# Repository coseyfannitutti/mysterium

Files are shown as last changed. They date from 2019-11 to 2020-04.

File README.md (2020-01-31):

# MYSTERIUM
**TKL keyboard that can be entirely assembled using only through hole components, including usb type c**

**[BOM, Build Guide, and Flashing Information](./doc)**

**Kits available at [cftkb.com](https://www.cftkb.com)**

**[Optional High Profile Lasercut Acrylic Case](./case)**

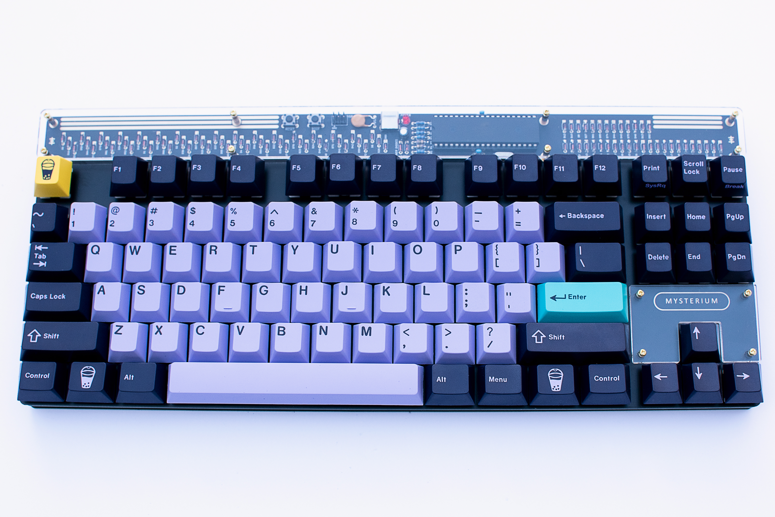
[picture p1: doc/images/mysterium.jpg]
mysterium

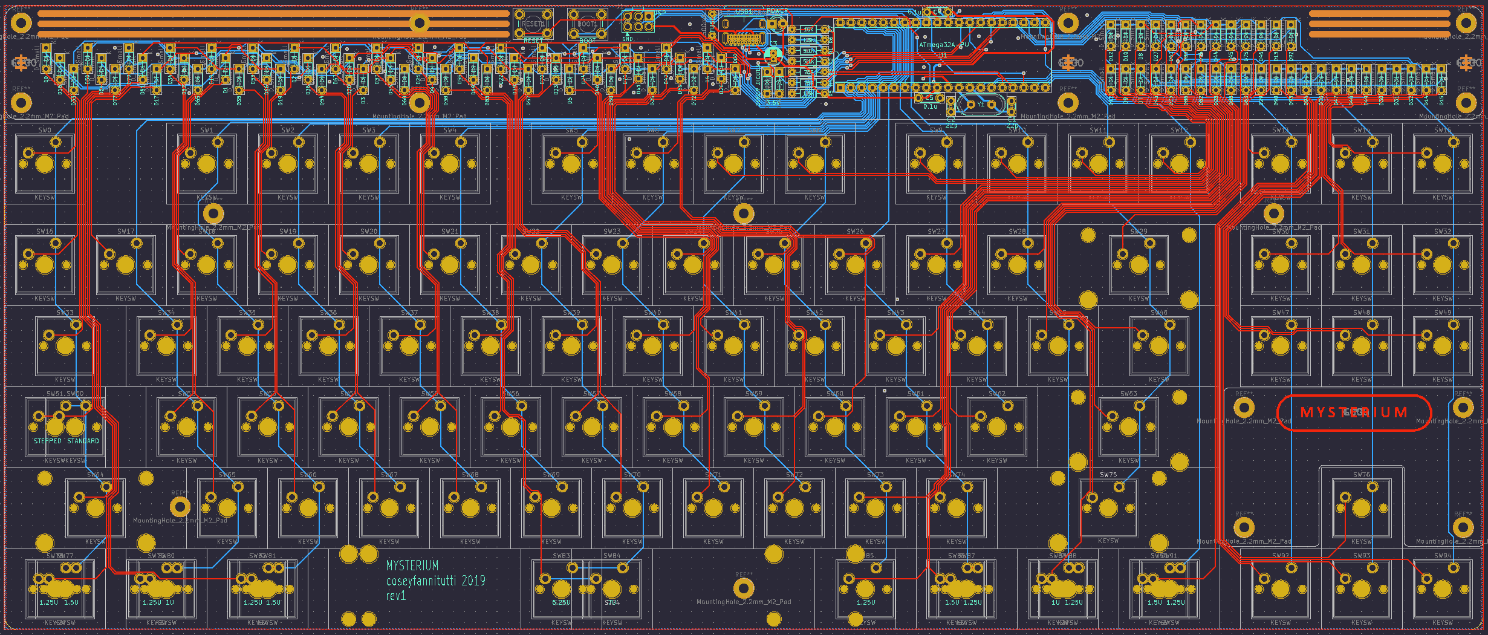
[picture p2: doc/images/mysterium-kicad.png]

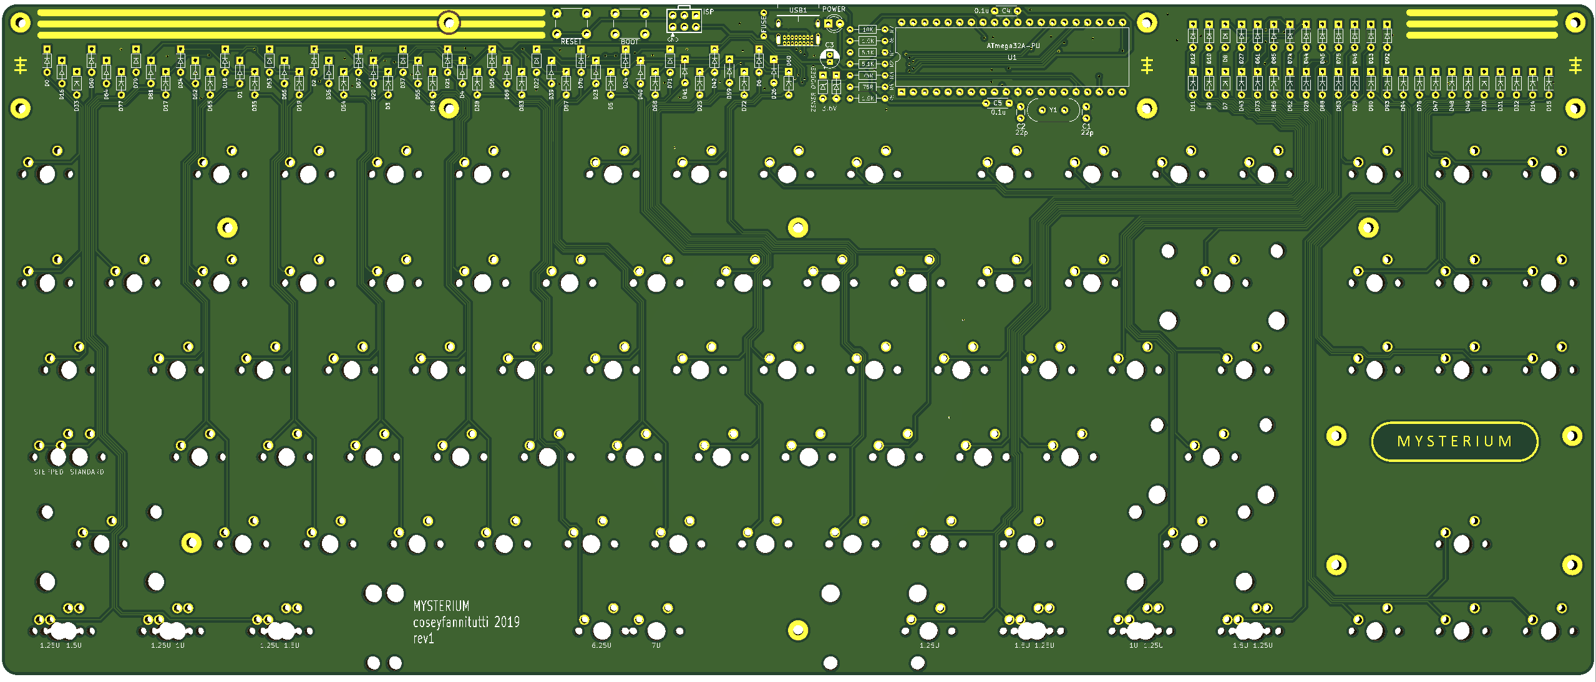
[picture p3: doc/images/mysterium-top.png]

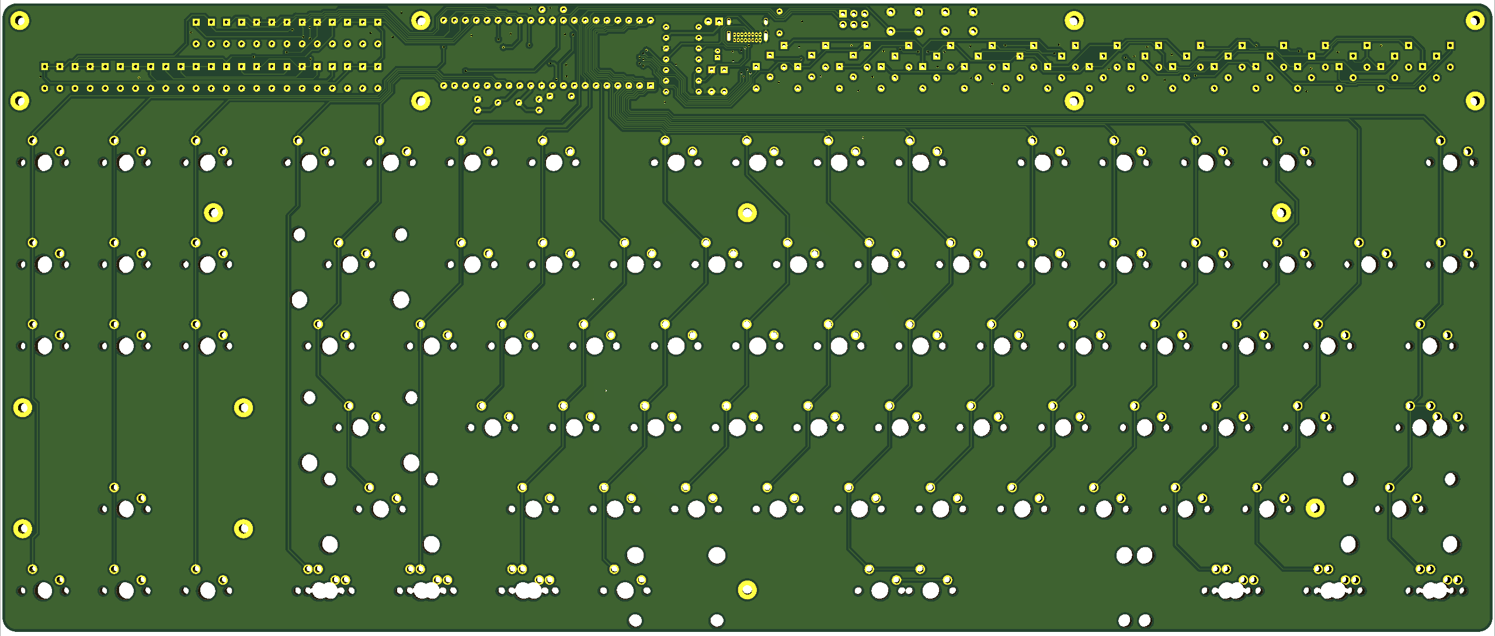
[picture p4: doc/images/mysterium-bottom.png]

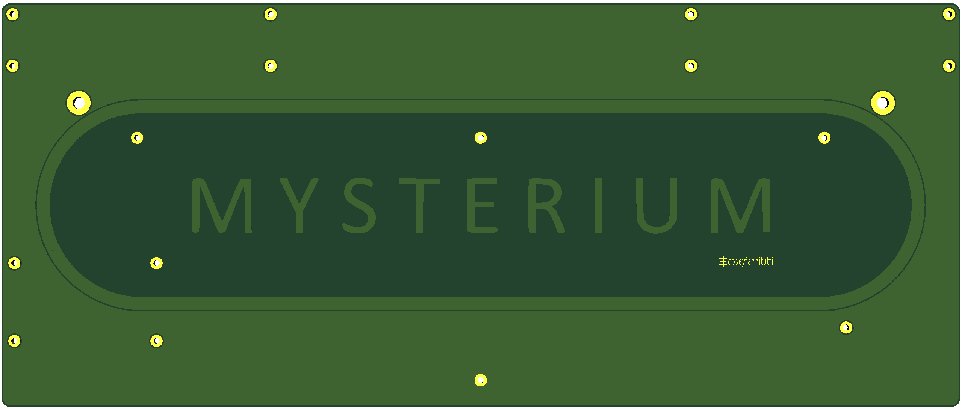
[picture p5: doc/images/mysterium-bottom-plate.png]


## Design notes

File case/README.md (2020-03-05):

# Lasercut Acrylic Case with POM Plate

***This is case is OPTIONAL and not required. The kit has everything you need for a fully functional keyboard.
This case uses a different plate and is NOT compatible with the plate included in the kit.
If you have already soldered switches, you will need to desolder them and swap the plate.***

***I recommend using [Ponoko](https://www.ponoko.com) to cut the pieces. They have all of the correct/required thicknesses and materials in stock and have the best pricing that I have found for multiple one-off parts. Use clear acrylic for the full range of thickness options and Delrin (POM) for the plate. For proper fit please ensure you use the correct dimensions and material thicknesses noted below. mysterium-top-1.dxf must be clear for component window. 3mm pieces will have full range of color options. 4.5mm open layer will have limited color choices but will only be visible from the side.***

***Ponoko's automatic size detection when uploading is not flawless, so be sure to manually enter the dimensions below.***

## Part Dimensions/Thickness (Top to Bottom)
1. mysterium-top-1.dxf - 363.7 x 162.6 mm - ***2mm thickness clear acrylic***
2. mysterium-top-2.dxf ***x2 needed*** - 363.7 x 162.6 mm - ***3mm thickness acrylic (Matte/frosted or color recomended for winkeyless version to hide plate hole.)***
3. mysterium-plate.dxf - 363.7 x 162.6 mm - ***1.5mm thickness DELRIN(POM)*** Can be black or white.
4. mysterium-open-layer.dxf - 363.7 x 162.6 mm - ***4.5mm thickness acrylic***
5. mysterium-closed-layer.dxf - 363.7 x 162.6 mm - ***3mm thickness acrylic***
6. mysterium-bottom.dxf - 363.7 x 162.6 mm - ***3mm thickness acrylic***
7. mysterium-foot-1.dxf - 323.7 x 32mm - ***3mm thickness acrylic***
8. mysterium-foot-2.dxf - 319.7 x 28mm - ***3mm thickness acrylic***
9. mysterium-foot-3.dxf - 315.7 x 24mm - ***3mm thickness acrylic***
10. mysterium-foot-4.dxf - 311.7 x 20mm - ***3mm thickness acrylic***

## Screws and Standoffs
1. [32x m2x6mm screws](https://www.aliexpress.com/item/32870342767.html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,searchweb201602_7,searchweb201603_53)
2. [12x m2x14mm standoffs](https://www.aliexpress.com/item/32968906213.html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,searchweb201602_7,searchweb201603_53)
3. [4x m2x8mm standoffs](https://www.aliexpress.com/item/32968906213.html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,searchweb201602_7,searchweb201603_53)

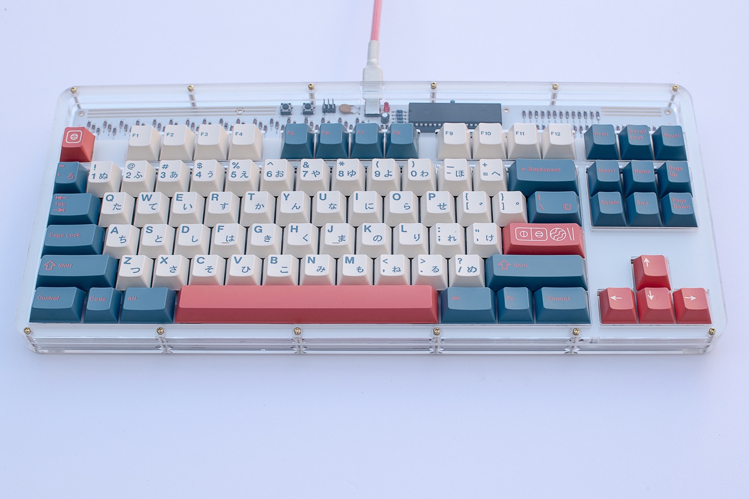
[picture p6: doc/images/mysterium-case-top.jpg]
mysterium

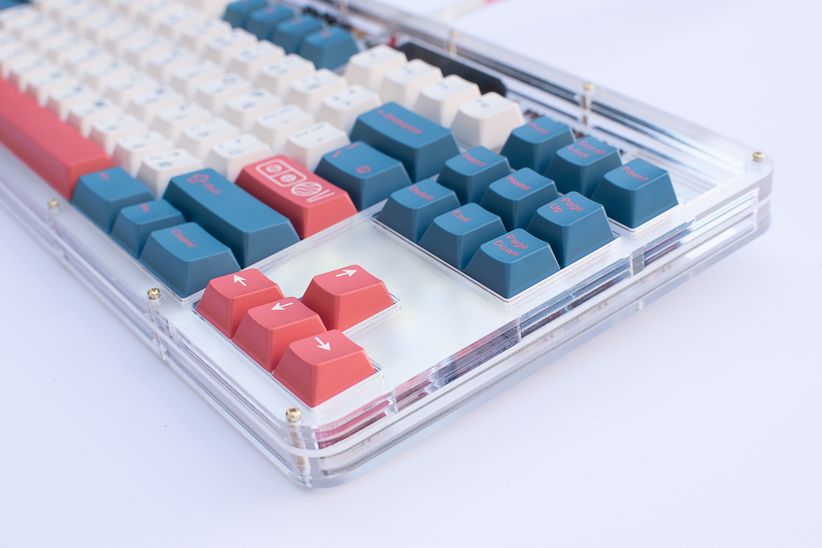
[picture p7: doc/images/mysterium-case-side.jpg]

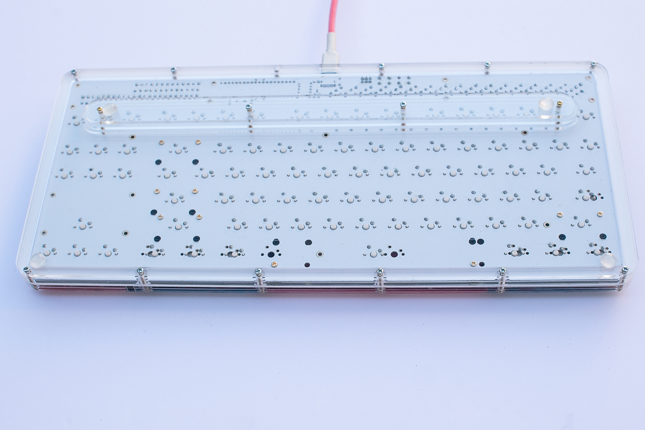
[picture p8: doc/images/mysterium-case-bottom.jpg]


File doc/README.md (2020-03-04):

# MYSTERIUM

mysterium

**[Build Guide](https://static1.squarespace.com/static/5c533d33348cd92b886e544d/t/5e5fc8299979957341bf18a8/1583335468613/MYSTERIUM+BUILD+GUIDE.pdf)**

**[QMK Toolbox Flashing Guide (Recommended)](https://static1.squarespace.com/static/5c533d33348cd92b886e544d/t/5e4771362bab65763e8d1e4c/1581740343418/MYSTERIUM+FLASHING+GUIDE.pdf)**

**[Command Line Flashing Guide (Advanced)](https://static1.squarespace.com/static/5c533d33348cd92b886e544d/t/5e33a3895318fc520982d4a1/1580442505724/MYSTERIUM+FLASHING+GUIDE+-+COMMAND+LINE.pdf)**

**[Bootloader](./bootloader)**

**[BOM (Parts List)](https://octopart.com/bom-tool/wr8C8imk)**

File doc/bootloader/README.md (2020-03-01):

# Bootloader

## If you buy a kit from cftkb.com your microcontroller already has the bootloader flashed and you do not need this.

This project uses USBaspLoader as the usb bootloader on the atmega32a.
- My custom bootloader:   
https://github.com/coseyfannitutti/USBaspLoader/tree/atmega32a
  - Please ensure you are in the atmega32a branch of my fork of the USBaspLoader repository when downloading.
  - Follow the directions in the readme for directions on setting up the build environment for your operating system as well as flash instructions.
  - Makefile.inc sets flashing device as usbtiny, as I use a sparkfun pocket avr programmer. If you need to use another programmer please edit line 41 of Makefile.inc accordingly. Only edit Makefile.inc, and NEVER directly edit the actual Makefile.
  - Commands for flashing once build environment is set up:
  
	```make flash``` (flashes makefile)
  
  	```make fuse``` (sets fuses for microcontroller)
  
## Enter bootloader mode
1. Press and hold ```BOOT``` switch
2. Tap ```RESET``` switch
3. Release ```BOOT``` switch

Alternatively, you can hold ```BOOT``` switch while inserting the USB cable.

If you have successfully entered bootloader mode you should see USBaspLoader in device manager or as a connected device in QMK Toolbox.

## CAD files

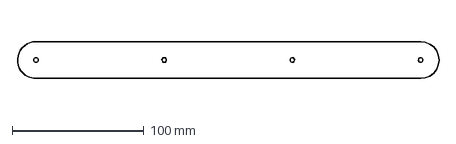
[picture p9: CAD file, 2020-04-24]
case/standard/mysterium-foot-2.dxf
321.4 x 28.0 mm

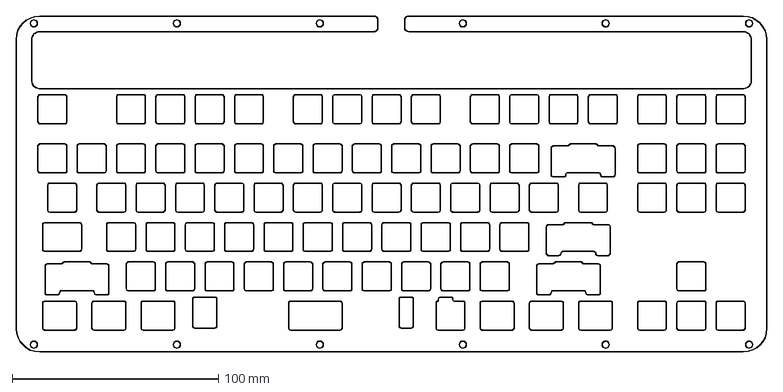
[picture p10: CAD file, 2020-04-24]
case/winkeyless/mysterium-plate.dxf
363.7 x 162.6 mm

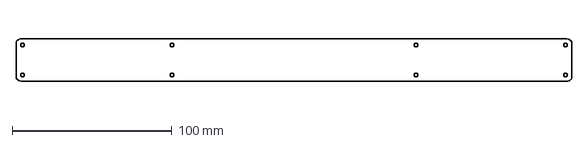
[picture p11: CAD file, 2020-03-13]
mysterium-acrylic-guard.dxf
347.7 x 26.8 mm

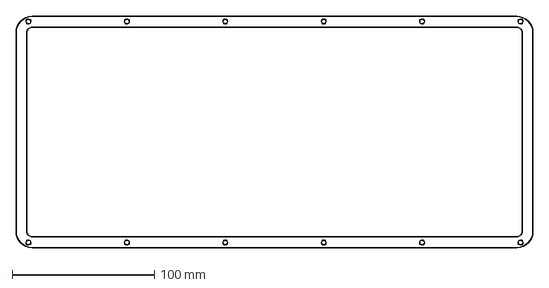
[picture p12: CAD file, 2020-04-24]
case/standard/mysterium-closed-layer.dxf
363.7 x 162.6 mm

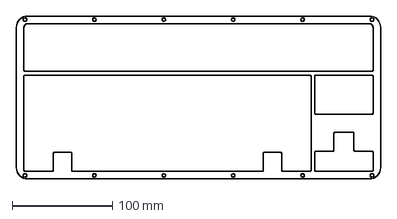
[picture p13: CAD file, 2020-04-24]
case/winkeyless/mysterium-top-2-wkl.dxf
363.7 x 162.6 mm

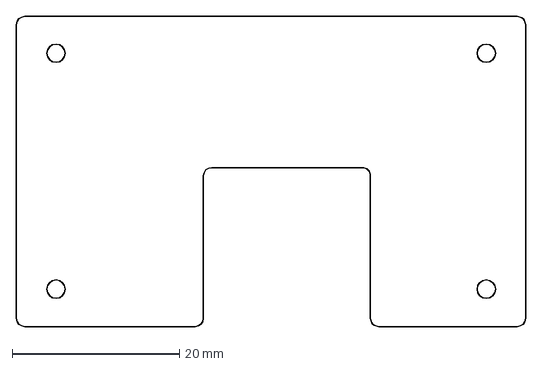
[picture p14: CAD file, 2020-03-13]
mysterium-nav-acrylic.dxf
61.0 x 37.2 mm

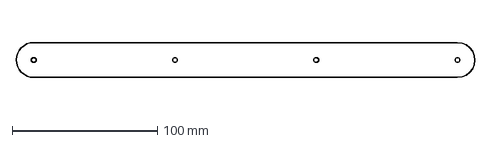
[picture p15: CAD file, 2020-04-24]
case/standard/mysterium-foot-3.dxf
316.2 x 24.0 mm

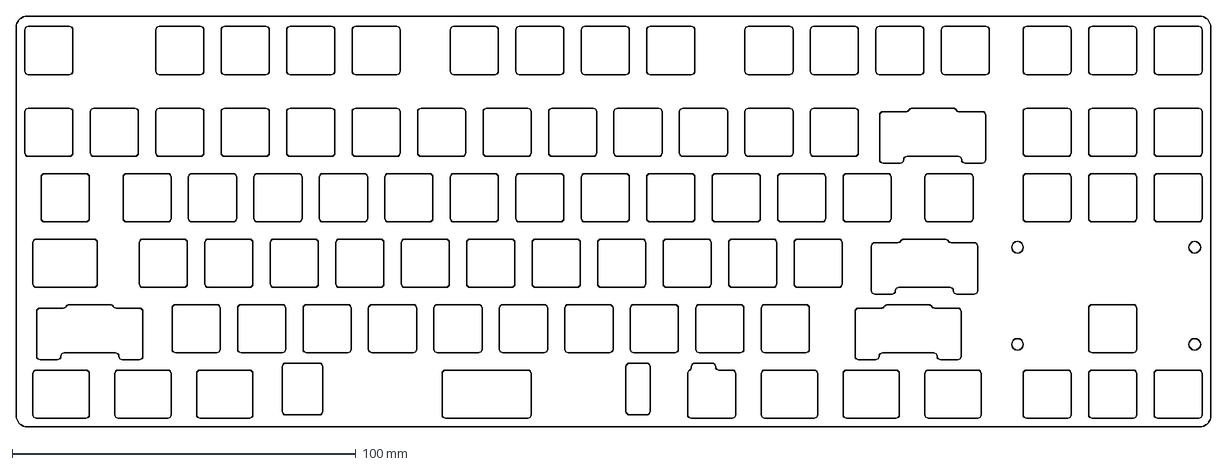
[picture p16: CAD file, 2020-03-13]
mysterium-kit-plate.dxf
347.7 x 119.5 mm

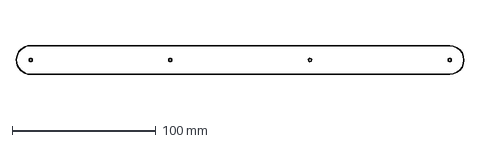
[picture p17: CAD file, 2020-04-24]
case/standard/mysterium-foot-4.dxf
312.1 x 20.0 mm

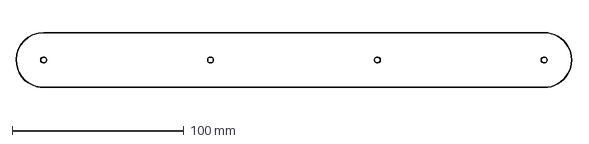
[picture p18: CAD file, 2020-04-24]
case/standard/mysterium-foot-1.dxf
324.4 x 32.0 mm

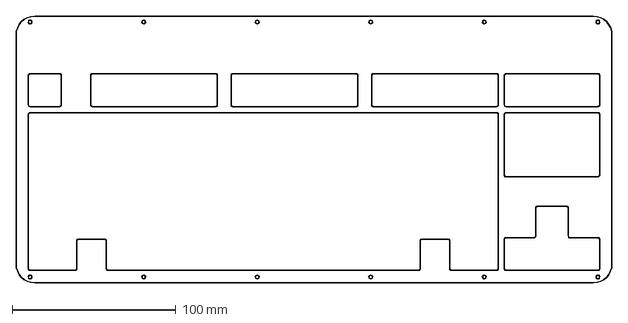
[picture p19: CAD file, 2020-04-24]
case/winkeyless/mysterium-top-1-wkl.dxf
363.7 x 162.6 mm

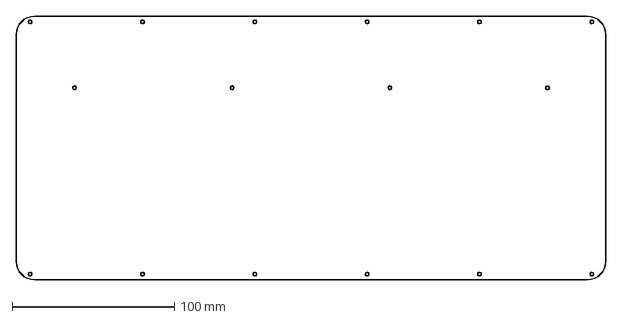
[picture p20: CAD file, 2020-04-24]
case/winkeyless/mysterium-bottom.dxf
363.7 x 162.6 mm

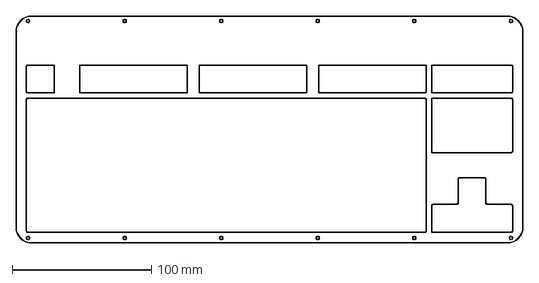
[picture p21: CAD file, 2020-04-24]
case/standard/mysterium-top-1.dxf
363.7 x 162.6 mm

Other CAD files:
case/standard/mysterium-open-layer.dxf
case/standard/mysterium-top-2.dxf
case/winkeyless/mysterium-open-layer.dxf

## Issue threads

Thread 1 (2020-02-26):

Board size is unknown

lackmorrison, 2020-02-26:
JLCPCB is not able to determine pcb size based on **mysterium.zip** archive. Please specify pcb size in readme
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

coseyfannitutti, 2020-02-26:
It's simply because it's a large board with a large drill file, and jlc's timeout limit sometimes doesn't give it enough time to process.

You will need to enter the dimensions manually (147mm*348mm).

Closed 2020-02-29.

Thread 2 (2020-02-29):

Switch plate files?

pigpenguin, 2020-02-29:
Thanks for open sourcing the design files, I'm a big fan of the board.

Was curious if the files for the switch plate were in the repository some where as I can't seem to find them.

lackmorrison, 2020-03-04:
Also build guide says that you need screw-in stabilizers because there is no plate. Can plate mounted stabs be used if there is a plate?

coseyfannitutti, 2020-03-04:
@pigpenguin I have added a .dxf file for the plate to the repository.

@lackmorrison The plate included in the kit does not support plate mount stabilizers. It is possible to allow for plate mount stabilizers, but you would need to make your own plate, as it requires a different cutout than what is on the one I have uploaded.

My choice to use screw-in stabilizers even with a plate is simply due to them being significantly more popular with custom boards. They are also widely considered to be much better than plate mount, and I agree with that.

Thanks for pointing that out, though. I have removed the "because there is no plate" bit. That was accidentally carried over from the Discipline build guide because that kit did not come with a plate.

Closed 2020-03-05.

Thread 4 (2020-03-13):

Question on Nav-Acrylic.dxg

ytkwong, 2020-03-13:
Hey, the specs for nav-acrylic file seems to be off, it is showing me as 296.3mm x 180.6mm.

I just realized it might be an issue with Ponoko's website. Could i get the dimensions specs for the basic acrylic guards is it supposed to be 348.6mm (width) for acrylic guard and kit plate and 61mm for nav?

And is the plate file missing the "~" key? or it's just not showing on Ponoko

coseyfannitutti, 2020-03-13:
The plate has now been fixed. Please update the repository or redownload for the correct files.

Plate and acrylic guard width: 347.7mm
Nav guard width: 61mm

I'm not sure how that cutout was removed when exporting, but thanks for pointing it out.

Closed 2020-03-13.

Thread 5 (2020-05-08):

windows cannot recognize USBaspLoader device

marklai1998, 2020-05-08:
I'm making my own mysterium and I bought my own chip
after flashing the bootloader with usbTiny
Windows doesn't recognize the device
how can I troubleshoot it?

coseyfannitutti, 2020-05-08:
If you ran both the 'make flash' and 'make fuse' commands without any errors, and it is still not working, then something on the board is not properly soldered.

marklai1998, 2020-05-08:
Thx for the reply, I'm a newbie in electronics, thus came here for help.

What I can tell is:

1. I swap out some parts since that's not common in my place. First one is the UMT1H4R7MDD, I swap out for a taller one, still 4.7uF 50V but its 85°C, not 105. Another one are those resistors, I cannot find 1/6w and used 1/5w instead

2. we found the led is soldered in the opposite way, causing the light won't on, but not sure if it will cause the board not booting

3. I tried to use WinAVR at first but it won't make. After switching to another AVR toolchain, it makes, but also come with some error.

make
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

make flash
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

make fuse
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

I'll keep investigating it, and get back to you in a few days

marklai1998, 2020-05-08:
When I use WinAVR, it won't even make
wanna make sure the make file is okay
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

coseyfannitutti, 2020-05-08:
You will need to [download and unzip this file](http://www.madwizard.org/download/electronics/msys-1.0-vista64.zip).
Copy msys-1.0.dll to the \utils\bin directory of your WinAVR folder

That will take care of the child died before initialization error.

marklai1998, 2020-05-09:
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
still no luck with the dll loaded

coseyfannitutti, 2020-05-09:
You don't need to run the 'make' command. You only need 'make flash' and 'make fuse'.

marklai1998, 2020-05-09:
I directly use `make flash` then `make fuse` but still no luck(using both a new chip and old chip)
I verified the soldered with a voltmeter, the USB port is working without any bridging(date + - pin are also connected)

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

coseyfannitutti, 2020-05-09:
Are you certain that your crystal is 16MHz / 18pF?

Something between your USB port and your microcontroller is not right, and this appears to be a physical issue on the PCB. Without having the board physically in my hand, it will be difficult for me to troubleshoot a physical issue.

It appears that the bootloader has been flashed correctly. The bootloader works, and the PCB design works. If you had this PCB made yourself, the minimum order was likely 5. I would recommend trying to rebuild if you cannot find what is wrong on the PCB.

marklai1998, 2020-05-09:
Yes, I'd have 5 board on my hand, I'll try to rebuild one in these few days.
Thx a lot, I'll update you after that

marklai1998, 2020-05-29:
sorry for a long silence. I've been back and forth around those 5 board these days.
I've been following your instruction and focus on the USB port. Greate news is that I've made 2 board working. Since 4 of my friends and I started this project. I still need to get the rest of the board working.

1 of the board act weirdly despite the USB port is soldered correctly. It starts out okay, can use for a few hours without a problem, but it stops working somehow when I reconnect the cable. And the data pins show they are connected, but somehow with a fluctuate and high resistance(sometimes it is 300ohm sometimes it is 5-600ohm)

Klagelied, 2021-06-01:
Hi,

I had the exact same problem with the Unknown USB Device (Device Descriptor Request Failed) Code 43. Only difference is that the problem affected my Discipline Keyboard, not my Mysterium.
Bootloader flashing and Firmware flashing worked great.

Next step was soldering the switches. After I hit the reset button, the error displayed. The board was tested before the switches were installed by me.
I triple checked my Soldering, on the USB-C connector as well as on the other components that were directly connected to the MCU or the USB-Port.

My luck was that I got hands on a notebook that did not showed me the Unknown USB Device (Device Descriptor Request Failed) error. It seemed that some Keys were stuck in action, like they were permanently pressed - Maybe it is a security feature by Windows to disable the USB-Device with such behaviour. Resoldering the problematic switches did the trick. My Discipline now works on any Windows PC.

Good luck on solving your issue!

Closed 2024-09-18.

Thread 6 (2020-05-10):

Proton C support

ytkwong, 2020-05-10:
Wondering if it was possible to directly replace the  Atmega with a proton C module?

coseyfannitutti, 2020-05-13:
Not with the design as it is. It can be adapted to be compatible, but schematic symbol/pcb footprint of the microcontroller would need to be replaced, rows and columns reassigned, many of the resistors and the zener diodes would need to be removed, and the firmware would need to change.

It’s certainly possible and wouldn’t be too difficult of a task if you’re familiar with kicad and qmk, but it’s far from simply buying a proton c and soldering it on the board as it is.

Closed 2020-05-13.

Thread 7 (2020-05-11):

Included components in build guide

austinmccalley, 2020-05-11:
I am an electrical engineering student I am trying to build this bord. I have the means necessary to print the PCB, but I am looking through the "included components," and I am confused about a couple of things.

Is the Atmega32A is this the Atmega32A-PN or Atmega32A-PU?
Could you also provide more information about the six-pin header?
Also, with the 500mA resettable fuse (5.1mm), what does the 5.1mm stand for?
Then with the 34x m2 mm screw, what part is this exactly?

If you could help me out, that would be great! If you could provide part numbers, that would be amazing.

austinmccalley, 2020-05-19:
Read deeper into the build guide and found it all.

Closed 2020-05-19.

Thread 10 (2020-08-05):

How to add capslock lights in qmk

kikko233, 2020-08-05:
i find gpio 32 not be used，i want to use this gpio with caps light. But i don't know how to set up in qmk，please help me ,think you very very much

nchieng, 2020-08-19:
Disclaimer: I have not yet flashed any keyboards with QMK as they are all still enroute. I have looked at the documentation a little to learn.

Without knowing what board/mcu/driver you have, there's only so much one can assume.

This [LED Control](https://docs.qmk.fm/#/custom_quantum_functions?id=led-control) documentation pretty mail nails it. You might just need to figure out what GPIO 32 corresponds to for your specific board.

You will need to ensure a few things have been done:

1. config.h
```c
/* Mechanical locking support. Use KC_LCAP, KC_LNUM or KC_LSCR instead in keymap */
#define LOCKING_SUPPORT_ENABLE
/* Locking resynchronize hack */
#define LOCKING_RESYNC_ENABLE
```

KolCrooks, 2020-12-07:
@kikko233 did you ever figure out how to add a caps light? I was thinking about adding one to my keyboard.

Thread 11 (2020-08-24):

JLCPCB problem with Gerber files

BenediktWoermann, 2020-08-24:
Hi!
I have planed to order a pcb of mysterium keyboard at jlcpcb, but the included zip in this repo isn't recognized / theres no gerber preview. At the discipline, all of this works great! I tried to make my own gerbers with kicad with the required settings specified by jlcpcb but nothing changed. Is this a bug in the pcb file or in the system of jlc?
Any help is greatly appreciated!
Note: I've not uploaded the files before July, as stated on their website, but today

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

BenediktWoermann, 2020-08-24:
Also, if I try to open the zip gerber in this repo with the gerber viewer in kicad, I get tons of error caused by unexpected chars in any of those gerberfiles...

coseyfannitutti, 2020-08-24:
It's a bug with JLC's gerber viewer timing out before it generates the preview. This can sometimes happen with large boards or large drill files, which take a long time to process.

You'll need to enter the dimensions manually, 347.8 x 146.8mm, for both the main PCB and the bottom plate PCB.

You unfortunately won't be able to see a gerber preview on JLC's site with Mysterium. If you would like to see a preview before ordering you can upload the .zip file to https://tracespace.io/

coseyfannitutti, 2020-08-25:
What version of KiCad are you using? I am not experiencing any errors opening the .zip with gerbview at all.
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

BenediktWoermann, 2020-08-25:
After loading file by file into gerbview i recognized that the drill files weren't loaded correctly, but I think this was my fault, because I used "open Gerberfiles" for opening the .pdf. If I use "open zip archive file" everythinng works in gerbview.
I also recognized, that if I leave out the drill files, jlc shows a preview, so maybe your right and they are just to big to process in time. I'll try ordering the way you suggested! But I have one more question: In the preview without the drillfiles I can see that the color of the pcb (and more importantly the color of the three lines at the top left) depend on the surface finish I choose. Is this really the case? Which one would you suggest to get this nice gold color seen in the build guide? Options are HASL (with lead), LeadFree HASL-RoHS and ENIG-RoHS. Thank you very much!

BenediktWoermann, 2020-08-27:
Think I figured it out, HASL is silverish and ENIG is golden. Nevertheless took HASL, because its around 20$ cheaper.

Closed 2020-08-27.

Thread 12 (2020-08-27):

Foam thingy from the kit

lackmorrison, 2020-08-27:
I couldn't find the file and thickness instructions for the foam that i've seen in the kit unboxing video. Can you add that to the repo? Also is this foam compatible with high profile case? Thank you.

derwana, 2020-10-05:
I think you can use `bottom/mysterium-bottom.kicad_pcb` to export a file for cutting, as it got all the holes and the overall shape. As of material i'd suggest one that is non conductive and as thick as the soldering joints on the PCBs back (e.g. 1.5mm).

dayofdoom, 2020-11-25:
@lackmorrison let me assure you, the foam recieved from the kit is **not** compatible with the high profile case.

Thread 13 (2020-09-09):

Adding LEDs

stevenvo, 2020-09-09:
Is it possible to add LEDs or any type of lighting to the board?

Kimo47, 2020-09-09:
LED strip can be added by connecting GND and +5v on the underside of the ISP headers. Not sure about programmability.

source: u/thearctican @ [https://www.reddit.com/r/MechanicalKeyboards/comments/f5kbc6/cftkb_mysterium_transparent_grey/](https://www.reddit.com/r/MechanicalKeyboards/comments/f5kbc6/cftkb_mysterium_transparent_grey/)

debido666, 2020-09-09:
It uses an ATMEGA32A-PU. (V2 model)
I imagine (hope) one just needs to find the right pin for addressing and add/enable RGB functions in firmware.
Guess I'll find out in October. When mine arrives.

d1554573r, 2020-09-20:
There is a similar topic in the discipline issues section. I'm trying to get this sorted but I get an unrecognized USB device error after flashing the firmware. I guess we can use a pin already taken for rows or columns?

Anyway, QMK supports only certain types of LED strips: https://beta.docs.qmk.fm/using-qmk/hardware-features/lighting/feature_rgblight

LEDs have to be enabled in rules.mk and configured in config.h by uncommenting LED part:

` #define RGB_DI_PIN A7
 #ifdef RGB_DI_PIN
   #define RGBLED_NUM 16
   #define RGBLIGHT_HUE_STEP 8
   #define RGBLIGHT_SAT_STEP 8
   #define RGBLIGHT_VAL_STEP 8
   #define RGBLIGHT_LIMIT_VAL 255 /* The maximum brightness level */
   #define RGBLIGHT_SLEEP  /* If defined, the RGB lighting will be switched off when the host goes to sleep */
// /*== all animations enable ==*/
   #define RGBLIGHT_ANIMATIONS
// /*== or choose animations ==*/
//   #define RGBLIGHT_EFFECT_BREATHING
//   #define RGBLIGHT_EFFECT_RAINBOW_MOOD
//   #define RGBLIGHT_EFFECT_RAINBOW_SWIRL
//   #define RGBLIGHT_EFFECT_SNAKE
//   #define RGBLIGHT_EFFECT_KNIGHT
//   #define RGBLIGHT_EFFECT_CHRISTMAS
//   #define RGBLIGHT_EFFECT_STATIC_GRADIENT
//   #define RGBLIGHT_EFFECT_RGB_TEST
//   #define RGBLIGHT_EFFECT_ALTERNATING
 #endif`

I bet the problem I got is because A7 is already used as a column pin, I struggle to understand which pins are BX, CX and DX as this naming doesn't match ATMEGA32A pinout schematic.

stevenvo, 2020-09-21:
the guide mentions D71 pin used for ISO, I wonder if we can use it to control the rgb...

d1554573r, 2020-10-01:
According to the schematic, only C0 & C0 are not taken but if you assign any of them to the LED's you'll get an unrecognized device. Atm I got fixed blue LED's and I would love to replace them with an RBG led.

this-snow, 2020-12-27:
> According to the schematic, only C0 & C0 are not taken but if you assign any of them to the LED's you'll get an unrecognized device. Atm I got fixed blue LED's and I would love to replace them with an RBG led.

Using Pin 23 - C1 works fine. Controlling the RGB with defined Keys in the Keymap works fine.

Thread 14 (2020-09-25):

Full VIA support

leovander, 2020-09-25:
I haven't seen any updates to the mysterium hex on the VIA website, and I saw your note about the media keys in your comment linked below.

As of now is there any way to enable those media keys in VIA without having to have you compile a specific layout? Or should I just keep an eye out on the VIA website?

Thanks!

https://github.com/coseyfannitutti/mysterium/issues/9#issuecomment-641700514

coseyfannitutti, 2020-09-26:
Yeah, I'm sure it will update eventually. I'm not sure how often they recompile, but it has been fixed in QMK. Once VIA recompiles firmware on their end, media keys should work for all V-USB boards that have updated the firmware accordingly.

For now the only way is to download the latest version of the QMK repository and compile the firmware via command line. You can unzip the attached file below for the updated .hex, though.

[coseyfannitutti_mysterium_via.hex.zip](https://github.com/coseyfannitutti/mysterium/files/5286717/coseyfannitutti_mysterium_via.hex.zip)

Closed 2020-09-27.

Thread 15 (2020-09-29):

Question about standoff heights in Mysterium case.

nchieng, 2020-09-29:
https://github.com/coseyfannitutti/mysterium/blob/master/case/README.md#L25-L26

Calls for standoffs:
14mm for the case
8mm for the feet

Stacking the case layers, it totals 20mm
Stacking the feet layers, it totals 12mm

Was there a reason why shorter standoffs were prescribed?

dhanakane, 2020-09-29:
Are you taking into account that the top and bottom layers are only for the screws to pass through? The standoffs do not pass through all the layers of the case.

nchieng, 2020-09-29:
No, I'm not.
If the screws pass through Top-1 and Bottom,
How are these pieces held in place?

dhanakane, 2020-09-29:
The screws are only 4mm. So you have 4mm screw --> 14mm standoff <-- 4mm screw. About 2mm of the thread engages the standoff on each side. The top and bottom sides of acrylic have smaller holes that only allow the screw body to pass through but a standoff cannot.

nchieng, 2020-09-29:
I think I get it. Thanks for the explanation!

So the top and bottom layers are essentially getting clamped by the screw caps and the standoffs.

dhanakane, 2020-09-29:
Yes! And the acrylic layers the screw threads pass through. The standoffs
align the case and provide a body for the screws to thread into as well.

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

coseyfannitutti, 2020-09-29:
That table is great. So, yes the standoff area length is ~15mm, and 14mm standoffs are used because of the slight variance in layer thickness of cast acrylic sheets.

It is the same for the feet, with ~9mm standoff area length, so 8mm standoffs are used.

nchieng, 2020-09-30:
Thanks! That now makes sense to me.

Here's the same table for the feet.
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

nchieng, 2020-09-30:
@coseyfannitutti
Sorry to keep this alive. Can you point me in the right direction for the clear bumpons users at the bottom of the case please?

dhanakane, 2020-09-30:
They’re very similar to these “3M Bumpon Protective Products SJ5312 Blister of 56”

They’re widely used in domestic applications.

Sent from my iPhone

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

Closed 2020-09-29.

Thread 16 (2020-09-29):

General USB connectivity question

dhanakane, 2020-09-29:
When using a USB switcher to switch between devices, I observe a lag and sometimes a complete lack of connectivity. This is resolved by plugging and unplugging the USB cables. Switching always requires a replug of the cables if it is the first time a device is being switched to after booting/awaking the computer being switched to.

I observe this problem using a Discipad as well. I have tried swapping cables, but the issue does not go away.

There is also a marked "lag" detecting the device. Is there a reason for this?

I notice this issue on MacOS, but I can test with Raspbian if required. I have tried troubleshooting with dmesg to see if there are any errors, but I see none. It just looks like there is a delay before the device is recognised. If you have any tips on how to get the device to be recognised more reliably or to reduce the time to detection then that would be much appreciated.

coseyfannitutti, 2020-09-30:
No, at this time I am unsure of the root cause of it being detected slowly
on MacOS. This issue does not happen with Windows. When I find some time,
I'll look into it a bit more. It may be related to the Raw HID enabled
version of the firmware, which allows VIA compatibility. Typically pressing
the reset button a few seconds after connecting is an alternative to
unplugging and plugging back in. When I've got some free time, I'll see if
using the original firmware without Raw HID enabled eliminates the lag
issue on MacOS.

If you can beat me to it, though, you could try using firmware compiled
from https://config.qmk.fm/ or by manually compiling via command line with
any of the layouts besides the VIA layout, which will not have RawHID
enable, and let me know if that fixes your issue.

This is most likely a firmware issue, but not one that is able to be fixed
directly by me. This is likely something deep in QMK core code for V-USB
devices, which is the software-only implementation of USB for
microcontrollers like ATmega32A and ATmega328P, which do not have an
integrated USB controller.

On Tue, Sep 29, 2020 at 4:13 AM Dhana Kaneshayogan <notifications@github.com>
wrote:

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

dhanakane, 2020-10-03:
So, if it helps, I believe I compiled my keymap from the command line using the Makefile in QMK. I also have the same problem with the Discipline I built and occasionally the Discipad too.

The suggestion of using the reset button is a good one. I will use that. Could I understand what the Reset button is doing in this case? Is it just a simple reboot for the keyboard? If this consistently resolves the issue, then I will recut my case to incorporate a window to access the boot and reset buttons. And perhaps the 6 pin header too, unless I can flash the firmware over USB once the keyboard is in bootloader mode.

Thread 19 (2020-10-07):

Hello there, hope you are well. I'm having an issue with my Mysterium- the 7, U, J, and M keys are not registering at all. I replaced diodes 22 and 24 and ensured that pin 4 on the MC socket is soldered correctly. Any ideas on how I can fix this?

I0PNR, 2020-10-07:

coseyfannitutti, 2020-10-08:
Make sure the microcontroller is seated properly and that none of the pins going into the socket are damaged. Otherwise, it sounds like you've got some damage on that column somewhere, either a scratch deep enough to cut the trace, or a damaged pad underneath your solder. A jumper wire should fix this issue for you.

These keys are all chained together on the upper pad of all of those switch positions. The circuit is highlighted in the picture below.

To see where this chain is broken and where to place your jumper wire, you will need to also test your F6 key, which is also on the same circuit.

If your F6 key is working, the chain is broken between F6 and your 7 key, and a jumper between the upper pads of those two keys. If your F6 key is also not working, then the issue is between F7 and the highlighted pin on the microcontroller. If that is the case, a jumper between the upper pad of F7 and that pin on the microcontroller should fix it.
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

coseyfannitutti, 2020-10-08:
@I0PNR pinging you here because I caught a couple typos, and said F7 a few times, when F6 should be the key to be looking at.

IOPNR, 2020-10-09:
@coseyfannitutti Hello again Bryan, just now had the chance to look at the board followed your direction to success. I ran the jumper from F6 to 7 and the whole column is up and running. Thank you for your prompt response, clear direction, and willingness to help - Much appreciated!

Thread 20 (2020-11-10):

Gerber ZIP file not recognised by JLCPCB

nchieng, 2020-11-10:
**Reproduction Steps**
1. Create a new account on JLCPCB
2. Start a new quote
3. Select option to 'Add your Gerber file'
4. Upload the Mysterium.zip file from the Gerber folder

**Expected**
File is uploaded and processed successfully and a preview is generated. The PCB details are automatically filled in with dimensions and thickness.

**Actual**
File uploads complete, but a preview is never generated and the form is not populated.

I've tried re-zipping all the Gerber files myself and uploading that and am still encountering the same.

Could this be an issue with JLCPCB's parser, or could something be done with the Gerber files?

nchieng, 2020-11-10:
I've just tried the file on PCBway and it managed to generate a preview correctly.

coseyfannitutti, 2020-11-10:
Yes, it is simply an issue with JLCPCB's gerber preview parser sometimes timing out. Their preview that also populates dimesions automatically, seems to be heavily reliant on the drill file, which in this case is extensive due to how many through hole footprints are on the PCB.

It is fine to order as is from JLCPCB if you manually enter the dimensions.
PCB and bottom plate dimensions: 347.8 x 146.8mm

Closed 2020-11-10.

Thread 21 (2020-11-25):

high profile case USB-C port clearance

dayofdoom, 2020-11-25:
I had my high profile case created at Ponoko and it seems dead on. Everything fits great. The one exception is that the hole for the USB-C cable is very small. I've had to trim my cables surrounding connector to barely make it fit. It seems that another 1-2mm of clearance in either direction would improve the ease of use.

Closed 2021-08-03.

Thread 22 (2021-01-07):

Power surge in USB device

damiencap, 2021-01-07:
Just looking for some info. I assume if I encounter such an error in windows I have bridging between the USB header pins?

If so, have I just fried the board?  I've tried to clean up the pins but I'm a new to soldering so I'm not sure if the job is good enough at this point.

Now when I plug the keyboard in I get the "device connected" sound followed by the "device disconnected" sounds.

Just wondering if I'll need a new PCB or if there's potentially another issue at play.

IUEngineering, 2021-08-11:
Probably a short somewhere between VCC and GND. I would carefully look at the USB-C port and check for a solder bridge there.

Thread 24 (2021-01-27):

Mysterium ISO problem

Schwelles, 2021-01-27:
Hello,

I recently build a mysterium and when i try to flash ISO layout on it the whole 3rd row goes one to the right. So the ISO enter is on the DEL, the DEL is on END, the END moves to PG DN etc.
I quickfixed it by just moving that row 1 to the left and it seems to work fine, so at least i can use it with ISO.

I wrote a mail with no reply and also opened an Issue on the QMK github.

Hope you can help, thx.

TobbenTM, 2021-02-23:
I have the same problem, tried messing around with the keymap a bit, but didn't reach any good solutions. Would be really good if either @coseyfannitutti or someone else with better QMK knowledge could take a closer look!

HalfHeuslerAlloy, 2021-04-08:
Having a similar issue with a board from mechboards. 3rd row shifted and also the left slash key doesn't respond. I can re-solder to the ansi format but I'd prefer a working QMK iso config if possible.

HalfHeuslerAlloy, 2021-04-09:
I think I've fixed it, at least for my board layout. The key map was slightly off. I've submitted a pull request to the qmk github. In the mean time here is the changes I made to C:\Users\Matthew Vaughan\qmk_firmware\keyboards\coseyfannitutti\mysterium\mysterium.h

copy and paste the relevant section.

#define LAYOUT_tkl_iso( \
    K00,      K02, K03, K04, K05, K06, K07, K08, K09,      K0B, K0C, K0D, K0E, K0F, K0G, K0H, \
    K10, K11, K12, K13, K14, K15, K16, K17, K18, K19, K1A, K1B, K1C, K1D,      K1F, K1G, K1H, \
    K20, K21, K22, K23, K24, K25, K26, K27, K28, K29, K2A, K2B, K2C,           K2F, K2G, K2H, \
    K30, K31, K32, K33, K34, K35, K36, K37, K38, K39, K3A, K3B, K2D, K3D,                     \
    K40, K01, K41, K42, K43, K44, K45, K46, K47, K48, K49, K4A,      K4D,           K4G,      \
    K50, K51, K52,                K56,           K59, K5A,      K5C,      K5E, K5F, K5G, K5H  \
) \
{ \
    { K00, _x_, K02, K03, K04, K05, K06, K07, K08, K09, _x_, K0B, K0C, K0D, K0E, K0F, K0G, K0H }, \
    { K10, K11, K12, K13, K14, K15, K16, K17, K18, K19, K1A, K1B, K1C, K1D, _x_, K1F, K1G, K1H }, \
    { K20, K21, K22, K23, K24, K25, K26, K27, K28, K29, K2A, K2B, K2C, K2D, _x_, K2F, K2G, K2H }, \
    { K30, K31, K32, K33, K34, K35, K36, K37, K38, K39, K3A, K3B, _x_, K3D, _x_, _x_, _x_, _x_ }, \
    { K40, K41, K42, K43, K44, K45, K46, K47, K48, K49, K4A, K01, _x_, K4D, _x_, _x_, K4G, _x_ }, \
    { K50, K51, K52, _x_, _x_, _x_, K56, _x_, _x_, K59, K5A, _x_, K5C, _x_, K5E, K5F, K5G, K5H }  \
}

#define LAYOUT_tkl_iso_7u( \
    K00,      K02, K03, K04, K05, K06, K07, K08, K09,      K0B, K0C, K0D, K0E, K0F, K0G, K0H, \
    K10, K11, K12, K13, K14, K15, K16, K17, K18, K19, K1A, K1B, K1C, K1D,      K1F, K1G, K1H, \
    K20, K21, K22, K23, K24, K25, K26, K27, K28, K29, K2A, K2B, K2C,           K2F, K2G, K2H, \
    K30, K31, K32, K33, K34, K35, K36, K37, K38, K39, K3A, K3B, K3D, K2D,                     \
    K40, K01, K41, K42, K43, K44, K45, K46, K47, K48, K49, K4A,      K4D,           K4G,      \
    K50, K51, K52,                K56,                K5A,      K5C,      K5E, K5F, K5G, K5H  \
) \
{ \
    { K00, K01, K02, K03, K04, K05, K06, K07, K08, K09, _x_, K0B, K0C, K0D, K0E, K0F, K0G, K0H }, \
    { K10, K11, K12, K13, K14, K15, K16, K17, K18, K19, K1A, K1B, K1C, K1D, _x_, K1F, K1G, K1H }, \
    { K20, K21, K22, K23, K24, K25, K26, K27, K28, K29, K2A, K2B, K2C, K2D, _x_, K2F, K2G, K2H }, \
    { K30, K31, K32, K33, K34, K35, K36, K37, K38, K39, K3A, K3B, _x_, K3D, _x_, _x_, _x_, _x_ }, \
    { K40, K41, K42, K43, K44, K45, K46, K47, K48, K49, K4A, K01, _x_, K4D, _x_, _x_, K4G, _x_ }, \
    { K50, K51, K52, _x_, _x_, _x_, K56, _x_, _x_, _x_, K5A, _x_, K5C, _x_, K5E, K5F, K5G, K5H }  \
}

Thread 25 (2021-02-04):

Compatibility with Lenovo ThinkPad dock

sonic757, 2021-02-04:
I built a mysterium with the high profile case for a friend and he is having issues with keys being "stuck" down (not physically) when the keyboard is plugged into a Lenovo ThinkPad dock. Keys would repeat forever if held down then released, and stop when hit repeatedly again. This issue does not present itself when connected directly to any computers including the laptop WHILE it is in the dock. Is there any way to fix this assuming the dock is not faulty? I looked into other issues and it might be a QMK firmware issue, but any insight would be very helpful.

dinosv, 2021-02-15:
It seems to me like a QMK firmware issue. I had a keyboard without flashing working ok for about two months, I just flashed it and had the same problem. Now I have it connected directly to the computer.

starwader, 2023-01-23:
I have a similar issue, did you resolve it somehow?
Both keyboard and mouse freeze from time to time.
Not sure if it is only the issue with dock as I tested it with my old x61s thinkpad and it acts the same.

dinosv, 2023-01-24:
> I have a similar issue, did you resolve it somehow? Both keyboard and mouse freeze from time to time. Not sure if it is only the issue with dock as I tested it with my old x61s thinkpad and it acts the same.

Not really. I still use it with direct connection to the PC.

starwader, 2023-01-25:
I think this may be a problem with the Linux driver. I will investigate that when I have some time

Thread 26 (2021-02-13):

Right side column (SW15,SW32,SW49,SW94) not working

lednax, 2021-02-13:
Hey @coseyfannitutti, I recently built a Mysterium (No iso) but the right side column isn't working. I tested for continuity based on the schematics and it appears there IS continuity but wanted to get your expert opinion. The rest of the kb works fine.

Screenshot of the column:
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

Thank you in advance. I bet you get a ton of these.

lednax, 2021-02-13:
I tested continuity again and I'm leaning torwards a software issue. Is the `default` qmk not good for v1?

this-snow, 2021-02-13:
Did you tested continuity up to the Controller? And continuity between the diodes, that are for this column.
There is no software issue.

lednax, 2021-02-14:
Checked continuity again up to the controller and it was fine but then noticed a bent leg on the controller so I got it out an fixed that. Works fine now.

Closed 2021-02-14.

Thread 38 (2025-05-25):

Scheme of desoldering the cable cores "directly" to the contacts of the board

ev-kotov, 2025-05-25:
I messed up the type-c connector. The tracks are very shallow and cannot be repaired or soldered. I want to solder "directly", from the cores of the cable to the contacts on the board. Can you tell me which color of the cable core (white, yellow, red, green) to solder to which elements of the board?

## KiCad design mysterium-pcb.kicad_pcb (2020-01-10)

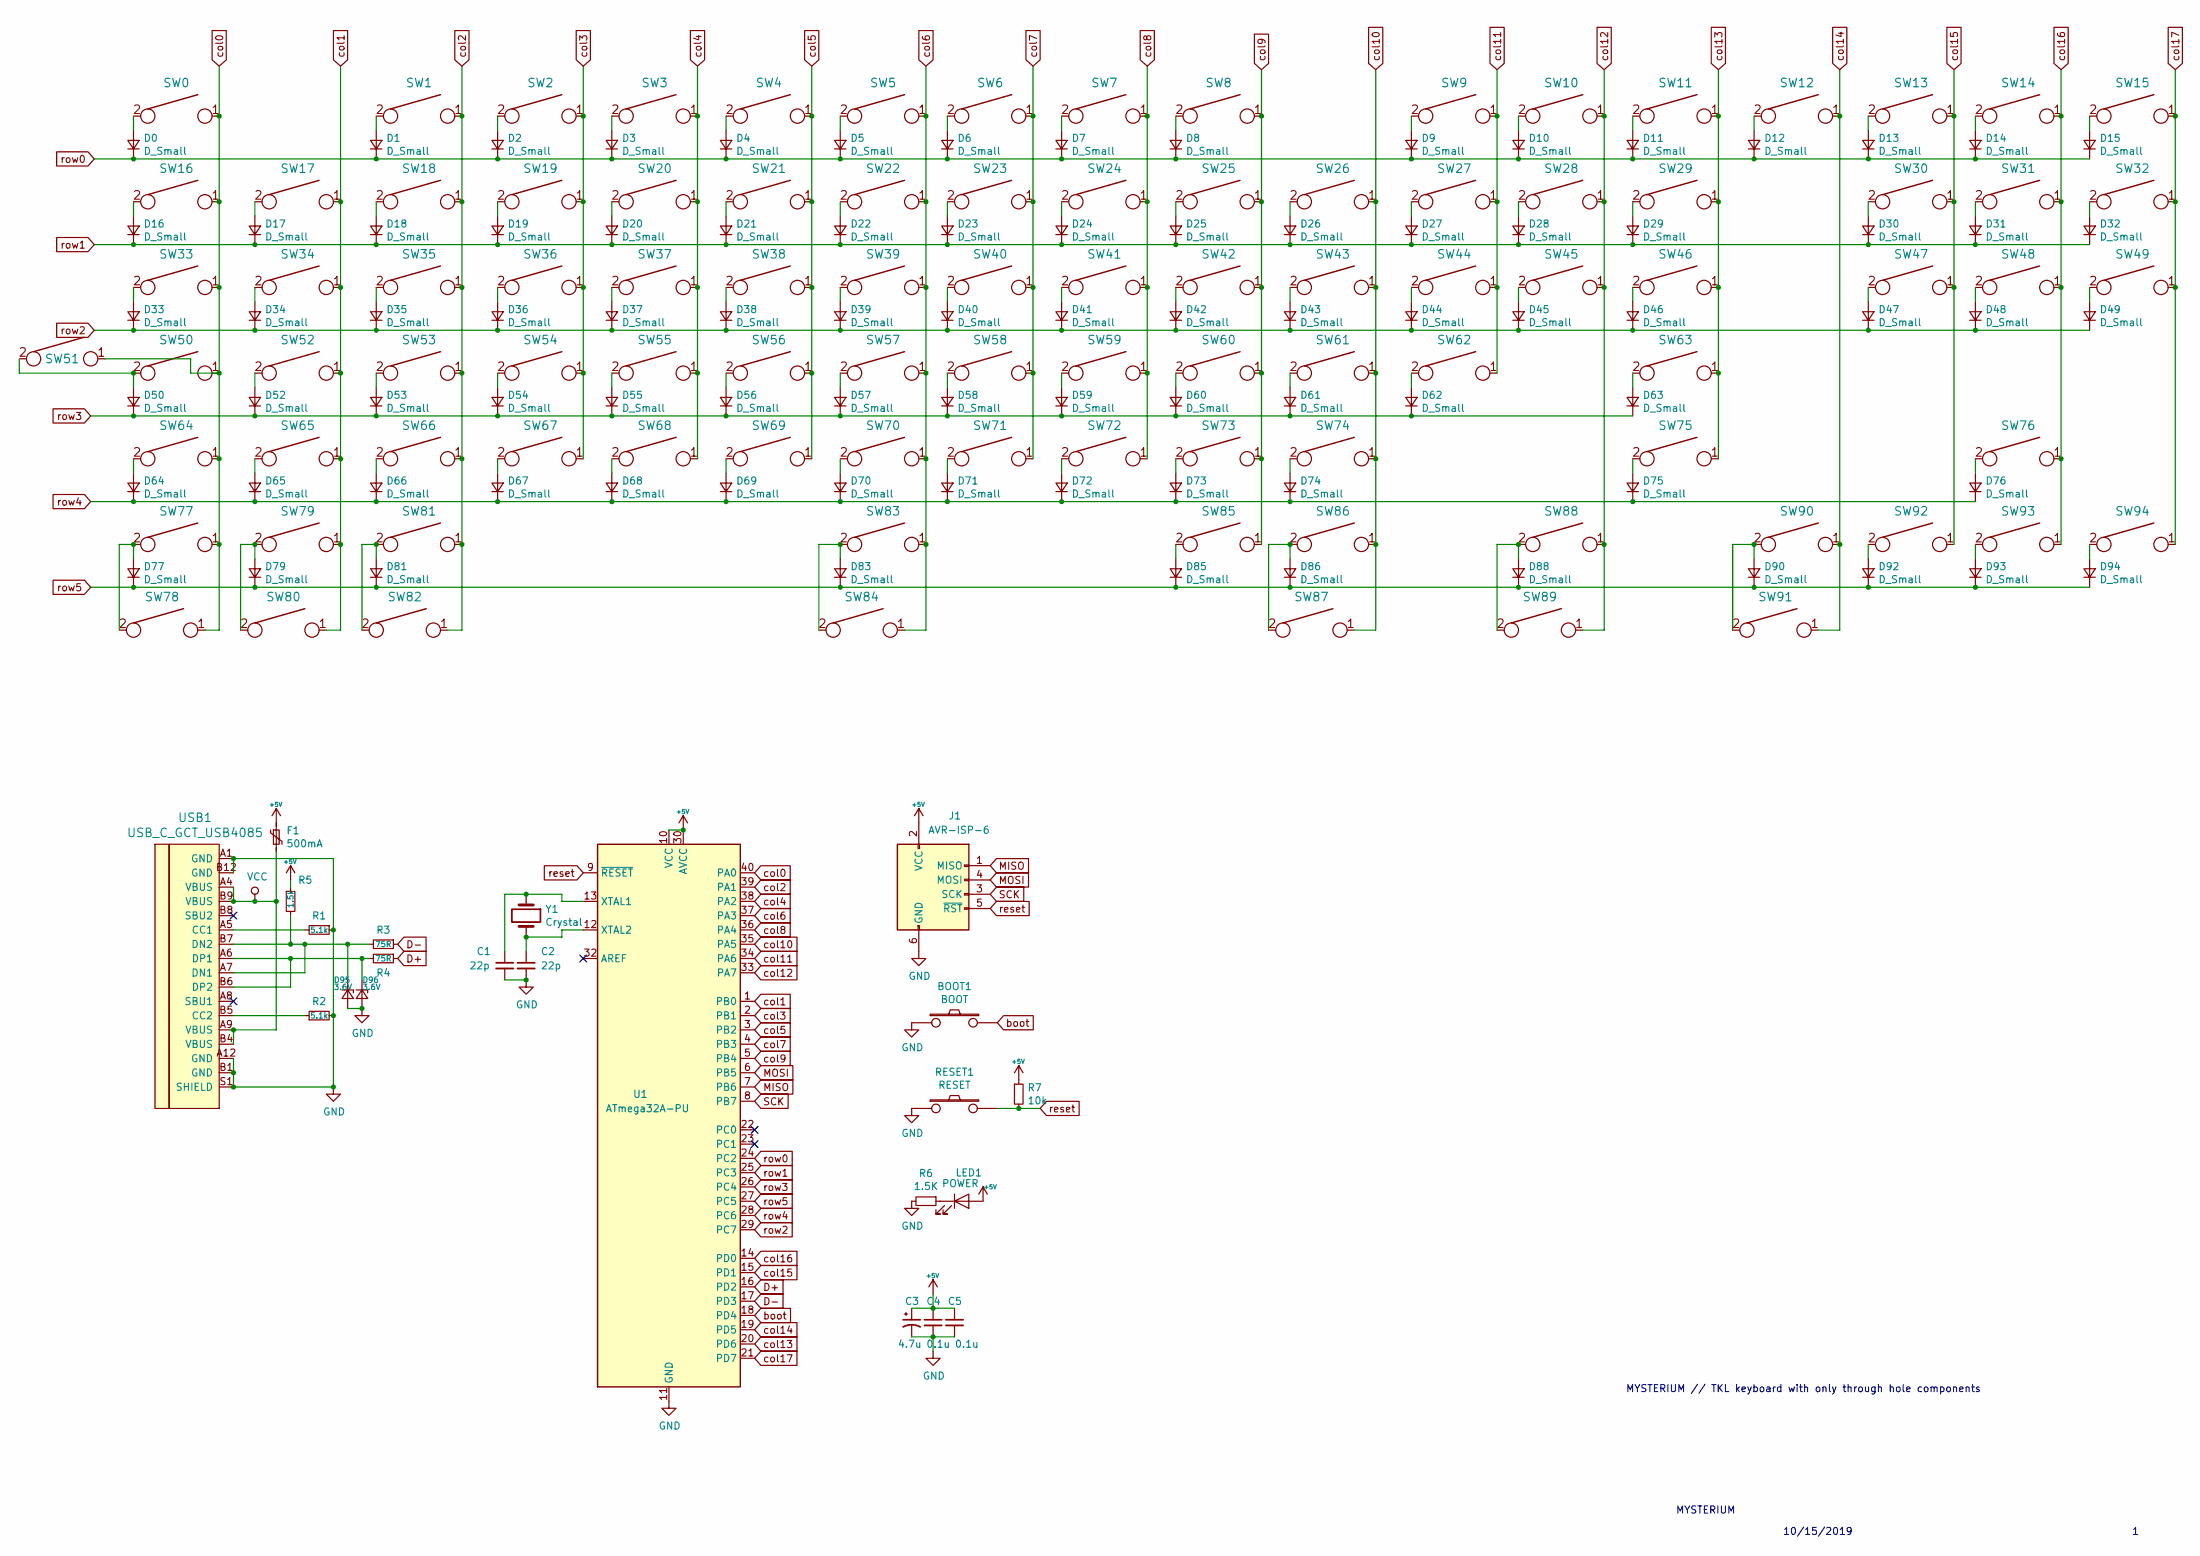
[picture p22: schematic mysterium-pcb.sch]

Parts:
BOOT1: BOOT; SW_PUSH_6mm
C1, C2: 22p; C_Disc_D3.0mm_W1.6mm_P2.50mm
C3: 4.7u; CP_Radial_D4.0mm_P1.50mm
C4, C5: 0.1u; C_Disc_D4.3mm_W1.9mm_P5.00mm
D0, D1, D2, D3, D4, D5, D6, D7, D8, D9, D10, D11, D12, D13, D14, D15, D16, D17, D18, D19, D20, D21, D22, D23, D24, D25, D26, D27, D28, D29, D30, D31, D32, D33, D34, D35, D36, D37, D38, D39, D40, D41, D42, D43, D44, D45, D46, D47, D48, D49, D50, D52, D53, D54, D55, D56, D57, D58, D59, D60, D61, D62, D63, D64, D65, D66, D67, D68, D69, D70, D71, D72, D73, D74, D75, D76, D77, D79, D81, D83, D85, D86, D88, D90, D92, D93, D94: D_Small; D_DO-35_SOD27_P5.08mm_Horizontal
D95, D96: 3.6V; D_DO-35_SOD27_P5.08mm_Horizontal
F1: 500mA; polyfuse_5.1mm
J1: AVR-ISP-6; AVR_ICSP_3x2
LED1: POWER; LED_D3.0mm
R1, R2: 5.1k; R_Axial_DIN0204_L3.6mm_D1.6mm_P7.62mm_Horizontal
R3, R4: 75R; R_Axial_DIN0204_L3.6mm_D1.6mm_P7.62mm_Horizontal
R5: 1.5k; R_Axial_DIN0204_L3.6mm_D1.6mm_P7.62mm_Horizontal
R6: 1.5K; R_Axial_DIN0204_L3.6mm_D1.6mm_P7.62mm_Horizontal
R7: 10k; R_Axial_DIN0204_L3.6mm_D1.6mm_P7.62mm_Horizontal
RESET1: RESET; SW_PUSH_6mm
SW0, SW1, SW2, SW3, SW4, SW5, SW6, SW7, SW8, SW9, SW10, SW11, SW12, SW13, SW14, SW15, SW16, SW17, SW18, SW19, SW20, SW21, SW22, SW23, SW24, SW25, SW26, SW27, SW28, SW30, SW31, SW32, SW34, SW35, SW36, SW37, SW38, SW39, SW40, SW41, SW42, SW43, SW44, SW45, SW47, SW48, SW49, SW52, SW53, SW54, SW55, SW56, SW57, SW58, SW59, SW60, SW61, SW62, SW65, SW66, SW67, SW68, SW69, SW70, SW71, SW72, SW73, SW74, SW76, SW80, SW83, SW84, SW89, SW92, SW93, SW94: KEYSW; SW_Cherry_MX1A_1.00u_PCB-NOSCREEN
SW29: KEYSW; SW_Cherry_MX1A_2.00u_PCBNOSCREEN
SW33, SW46, SW77, SW81, SW86, SW90: KEYSW; SW_Cherry_MX1A_1.50u_PCBNOSCREEN
SW50: KEYSW; SW_Cherry_MX1A_1.75u_PCBNOSCREEN
SW51, SW78, SW79, SW82, SW85, SW87, SW88, SW91: KEYSW; SW_Cherry_MX1A_1.25u_PCBNOSCREEN
SW63, SW64: KEYSW; SW_Cherry_MX1A_2.25u_PCBNOSCREEN
SW75: KEYSW; SW_Cherry_MX1A_2.75u_PCB_NOSCREEN
U1: ATmega32A-PU; DIP-40_W15.24mm
USB1: USB_C_GCT_USB4085
Y1: Crystal; Crystal_HC49-4H_Vertical

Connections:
+5V: C3.1, C4.1, C5.1, F1.1, J1.2 (VCC), LED1.2 (A), R5.1, R7.1, U1.10 (VCC), U1.30 (AVCC)
D+: R4.1, U1.16 (PD2)
D-: R3.1, U1.17 (PD3)
GND: BOOT1.1, C1.2, C2.2, C3.2, C4.2, C5.2, D95.2 (A), D96.2 (A), J1.6 (GND), R1.1, R2.2, R6.2, RESET1.1, U1.11 (GND), U1.31 (GND), USB1.A1 (GND), USB1.A12 (GND), USB1.B1 (GND), USB1.B12 (GND), USB1.S1 (SHIELD)
MISO: J1.1 (MISO), U1.7 (PB6)
MOSI: J1.4 (MOSI), U1.6 (PB5)
unnamed: C1.1, U1.13 (XTAL1), Y1.1
unnamed: C2.1, U1.12 (XTAL2), Y1.2
unnamed: D0.2 (A), SW0.2
unnamed: D1.2 (A), SW1.2
unnamed: D2.2 (A), SW2.2
unnamed: D3.2 (A), SW3.2
unnamed: D4.2 (A), SW4.2
unnamed: D5.2 (A), SW5.2
unnamed: D6.2 (A), SW6.2
unnamed: D7.2 (A), SW7.2
unnamed: D8.2 (A), SW8.2
unnamed: D9.2 (A), SW9.2
unnamed: D10.2 (A), SW10.2
unnamed: D11.2 (A), SW11.2
unnamed: D12.2 (A), SW12.2
unnamed: D13.2 (A), SW13.2
unnamed: D14.2 (A), SW14.2
unnamed: D15.2 (A), SW15.2
unnamed: D16.2 (A), SW16.2
unnamed: D17.2 (A), SW17.2
unnamed: D18.2 (A), SW18.2
unnamed: D19.2 (A), SW19.2
unnamed: D20.2 (A), SW20.2
unnamed: D21.2 (A), SW21.2
unnamed: D22.2 (A), SW22.2
unnamed: D23.2 (A), SW23.2
unnamed: D24.2 (A), SW24.2
unnamed: D25.2 (A), SW25.2
unnamed: D26.2 (A), SW26.2
unnamed: D27.2 (A), SW27.2
unnamed: D28.2 (A), SW28.2
unnamed: D29.2 (A), SW29.2
unnamed: D30.2 (A), SW30.2
unnamed: D31.2 (A), SW31.2
unnamed: D32.2 (A), SW32.2
unnamed: D33.2 (A), SW33.2
unnamed: D34.2 (A), SW34.2
unnamed: D35.2 (A), SW35.2
unnamed: D36.2 (A), SW36.2
unnamed: D37.2 (A), SW37.2
unnamed: D38.2 (A), SW38.2
unnamed: D39.2 (A), SW39.2
unnamed: D40.2 (A), SW40.2
unnamed: D41.2 (A), SW41.2
unnamed: D42.2 (A), SW42.2
unnamed: D43.2 (A), SW43.2
unnamed: D44.2 (A), SW44.2
unnamed: D45.2 (A), SW45.2
unnamed: D46.2 (A), SW46.2
unnamed: D47.2 (A), SW47.2
unnamed: D48.2 (A), SW48.2
unnamed: D49.2 (A), SW49.2
unnamed: D50.2 (A), SW50.2, SW51.2
unnamed: D52.2 (A), SW52.2
unnamed: D53.2 (A), SW53.2
unnamed: D54.2 (A), SW54.2
unnamed: D55.2 (A), SW55.2
unnamed: D56.2 (A), SW56.2
unnamed: D57.2 (A), SW57.2
unnamed: D58.2 (A), SW58.2
unnamed: D59.2 (A), SW59.2
unnamed: D60.2 (A), SW60.2
unnamed: D61.2 (A), SW61.2
unnamed: D62.2 (A), SW62.2
unnamed: D63.2 (A), SW63.2
unnamed: D64.2 (A), SW64.2
unnamed: D65.2 (A), SW65.2
unnamed: D66.2 (A), SW66.2
unnamed: D67.2 (A), SW67.2
unnamed: D68.2 (A), SW68.2
unnamed: D69.2 (A), SW69.2
unnamed: D70.2 (A), SW70.2
unnamed: D71.2 (A), SW71.2
unnamed: D72.2 (A), SW72.2
unnamed: D73.2 (A), SW73.2
unnamed: D74.2 (A), SW74.2
unnamed: D75.2 (A), SW75.2
unnamed: D76.2 (A), SW76.2
unnamed: D77.2 (A), SW77.2, SW78.2
unnamed: D79.2 (A), SW79.2, SW80.2
unnamed: D81.2 (A), SW81.2, SW82.2
unnamed: D83.2 (A), SW83.2, SW84.2
unnamed: D85.2 (A), SW85.2
unnamed: D86.2 (A), SW86.2, SW87.2
unnamed: D88.2 (A), SW88.2, SW89.2
unnamed: D90.2 (A), SW90.2, SW91.2
unnamed: D92.2 (A), SW92.2
unnamed: D93.2 (A), SW93.2
unnamed: D94.2 (A), SW94.2
unnamed: D95.1 (K), R3.2, R5.2, USB1.A7 (DN1), USB1.B7 (DN2)
unnamed: D96.1 (K), R4.2, USB1.A6 (DP1), USB1.B6 (DP2)
unnamed: LED1.1 (K), R6.1
unnamed: R1.2, USB1.A5 (CC1)
unnamed: R2.1, USB1.B5 (CC2)
SCK: J1.3 (SCK), U1.8 (PB7)
VCC: F1.2, USB1.A4 (VBUS), USB1.A9 (VBUS), USB1.B4 (VBUS), USB1.B9 (VBUS)
boot: BOOT1.2, U1.18 (PD4)
col0: SW0.1, SW16.1, SW33.1, SW50.1, SW51.1, SW64.1, SW77.1, SW78.1, U1.40 (PA0)
col1: SW17.1, SW34.1, SW52.1, SW65.1, SW79.1, SW80.1, U1.1 (PB0)
col2: SW1.1, SW18.1, SW35.1, SW53.1, SW66.1, SW81.1, SW82.1, U1.39 (PA1)
col3: SW2.1, SW19.1, SW36.1, SW54.1, SW67.1, U1.2 (PB1)
col4: SW3.1, SW20.1, SW37.1, SW55.1, SW68.1, U1.38 (PA2)
col5: SW4.1, SW21.1, SW38.1, SW56.1, SW69.1, U1.3 (PB2)
col6: SW5.1, SW22.1, SW39.1, SW57.1, SW70.1, SW83.1, SW84.1, U1.37 (PA3)
col7: SW6.1, SW23.1, SW40.1, SW58.1, SW71.1, U1.4 (PB3)
col8: SW7.1, SW24.1, SW41.1, SW59.1, SW72.1, U1.36 (PA4)
col9: SW8.1, SW25.1, SW42.1, SW60.1, SW73.1, SW85.1, U1.5 (PB4)
col10: SW26.1, SW43.1, SW61.1, SW74.1, SW86.1, SW87.1, U1.35 (PA5)
col11: SW9.1, SW27.1, SW44.1, SW62.1, U1.34 (PA6)
col12: SW10.1, SW28.1, SW45.1, SW88.1, SW89.1, U1.33 (PA7)
col13: SW11.1, SW29.1, SW46.1, SW63.1, SW75.1, U1.20 (PD6)
col14: SW12.1, SW90.1, SW91.1, U1.19 (PD5)
col15: SW13.1, SW30.1, SW47.1, SW92.1, U1.15 (PD1)
col16: SW14.1, SW31.1, SW48.1, SW76.1, SW93.1, U1.14 (PD0)
col17: SW15.1, SW32.1, SW49.1, SW94.1, U1.21 (PD7)
reset: J1.5 (~RST), R7.2, RESET1.2, U1.9 (~RESET)
row0: D0.1 (K), D1.1 (K), D2.1 (K), D3.1 (K), D4.1 (K), D5.1 (K), D6.1 (K), D7.1 (K), D8.1 (K), D9.1 (K), D10.1 (K), D11.1 (K), D12.1 (K), D13.1 (K), D14.1 (K), D15.1 (K), U1.24 (PC2)
row1: D16.1 (K), D17.1 (K), D18.1 (K), D19.1 (K), D20.1 (K), D21.1 (K), D22.1 (K), D23.1 (K), D24.1 (K), D25.1 (K), D26.1 (K), D27.1 (K), D28.1 (K), D29.1 (K), D30.1 (K), D31.1 (K), D32.1 (K), U1.25 (PC3)
row2: D33.1 (K), D34.1 (K), D35.1 (K), D36.1 (K), D37.1 (K), D38.1 (K), D39.1 (K), D40.1 (K), D41.1 (K), D42.1 (K), D43.1 (K), D44.1 (K), D45.1 (K), D46.1 (K), D47.1 (K), D48.1 (K), D49.1 (K), U1.29 (PC7)
row3: D50.1 (K), D52.1 (K), D53.1 (K), D54.1 (K), D55.1 (K), D56.1 (K), D57.1 (K), D58.1 (K), D59.1 (K), D60.1 (K), D61.1 (K), D62.1 (K), D63.1 (K), U1.26 (PC4)
row4: D64.1 (K), D65.1 (K), D66.1 (K), D67.1 (K), D68.1 (K), D69.1 (K), D70.1 (K), D71.1 (K), D72.1 (K), D73.1 (K), D74.1 (K), D75.1 (K), D76.1 (K), U1.28 (PC6)
row5: D77.1 (K), D79.1 (K), D81.1 (K), D83.1 (K), D85.1 (K), D86.1 (K), D88.1 (K), D90.1 (K), D92.1 (K), D93.1 (K), D94.1 (K), U1.27 (PC5)
scl: U1.22 (PC0)
sda: U1.23 (PC1)

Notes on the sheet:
MYSTERIUM // TKL keyboard with only through hole components
10/15/2019
MYSTERIUM

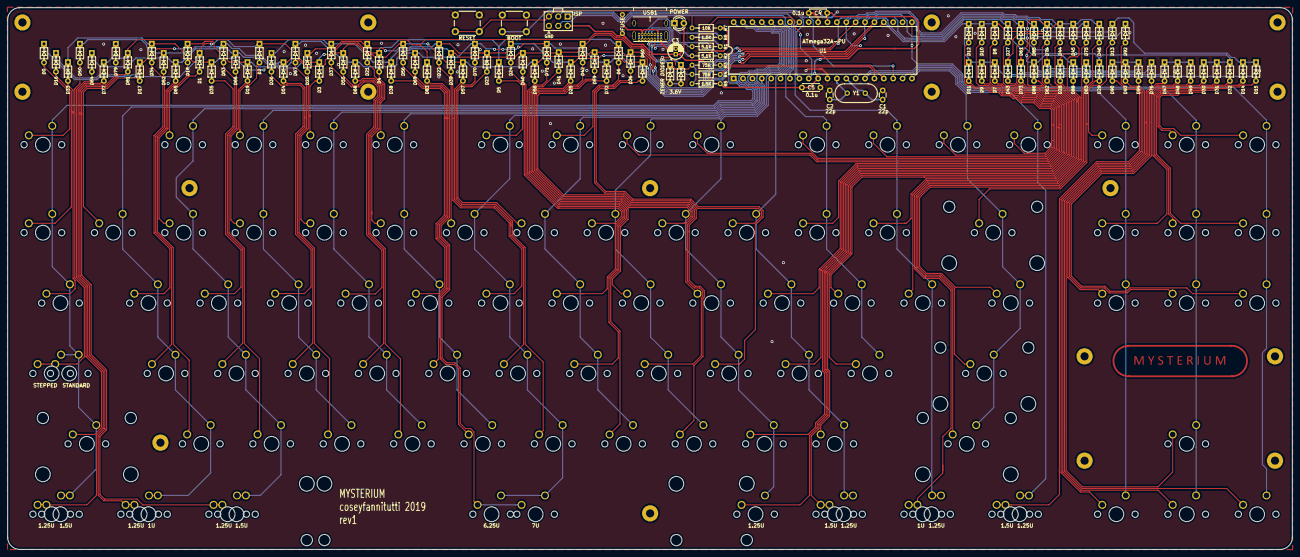
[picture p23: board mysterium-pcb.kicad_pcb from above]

Board: 2 copper layers, 347.7 x 146.6 mm, 206 parts (0 on the bottom side), 128 nets.

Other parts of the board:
ST83: 6.25U; MX-6.25U-Stabilizer
ST84: 7U; MX-7U-Stabilizer

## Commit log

2019-11-03 Update mysterium-pcb.kicad_pcb-bak
2020-01-31 separate standard and winkeyless
    [mysterium-bottom.dxf, mysterium-closed-layer.dxf, mysterium-foot-1.dxf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]
2020-04-24 fix scaling
    [mysterium-bottom.dxf, mysterium-closed-layer.dxf, mysterium-foot-1.dxf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]
